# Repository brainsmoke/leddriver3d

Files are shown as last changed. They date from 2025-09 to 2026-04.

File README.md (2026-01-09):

# LED Driver for 3D sculptures based on an ESP32 with PSRAM + an STM32F0XX

     







# Design:

```
   programming &
  micropython REPL
         ||
     .--------.
     |  usb   |
     |   to   |  unified codebase       project specific firmware
     | serial |    /                            \
     '--------'   /                              \
         ||      /   standardized protocol        \
   .--------------.            |                  _____________.--
   |  ESP32-D0WD  |          (UART)              |             |-- multiple LED strands
   |   8M PSRAM   |-- 16bit/color LED frames --> |  STM32F0XX  |-- (temporal dithered)
   |  16M FLASH   |                              |_____________|--
   '--------------'                                            '--

```

# ESP Code `firmware/esp32/`

- Running micropython

- 60 FPS 16bit/color (48bit) animation with some routines written in C for speed.

- Animations use 3D-coordinates of the LEDs, as well as the direction they're pointing at

- Gamma correction & support for multiple LED orderings.

- Cached animation frames to prevent garbage collection hiccups

- Web interface (HTTPS capable, but no automatic cert. updates)

# STM32 Code `firmware/stm32/`

## Protocol

Sending a frame: `( [16 bit brightness]* [ FF FF FF F0 ] )*`

Brightness must be little endian integers in the (inclusive) range `[0 .. 0xFF00]`

`[ FF FF FF F0 ]` is an end of frame marker and allows the protocol to synchronize
in the event of an uneven number of bytes being written to the serial port

The firmware is completely agnostic about the color ordering.

Some of the following firmwares allow for tuning of the pulse interval:

`( [16 bit number]* [ FF FF FF F3 ] )*`

The given number is the number of cycles outputting a byte should take.
(Useful for increasing the FPS and thus improving temporal dithering.

## `dither16.bin`

Read in 16bit/color data in, drive 8 ws2812 LED strips in parallel

## `strip4.bin`

Read in 16bit/color data in, drive 4 ws2812 LED strips in parallel

## `strip5.bin`

Read in 16bit/color data in, drive 5 ws2812 LED strips in parallel,
Supports tuning the pulse interval.

## `relayball.bin`

Read in 16bit/color data in, drive 4 circuit-routed ws2812 LED meshes.
Small LED strands are connected through PADAUK based relay-chips
(`firmware/pdk/relay/`) that use in-band messages to build up routing
circuits.

## `uartball16.bin`

Drives up-to 8 busses with PADAUK based LED drivers which read 38400 baud
uart. `firmware/pdk/softpwm/`

##  `dither8.bin`

Older code using a different input protocol, reads 8bit/color data & transforms this to 16 bit colors
after gamma correction

# STM32 Tester code

## `jitter_timer.bin`

Tester for PADAUK ws2812 relay chips. `firmware/pdk/relay/`





Tests for functionality and measures the clock speed deviation (for binning).

## `timing_experiment.bin`

Dynamically adjust the `T1H` and `T1L` intervals from the ws2812 protocol to
test its limits.



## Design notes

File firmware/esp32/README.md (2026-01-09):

# ESP32 firmware upload / build

## Upload pre-built firmware

```bash
# make sure you are a member of the dailout group (so you can talk to the serial device)
sudo usermod -a -G dialout "$USER"
# you might need to log in again for it to take effect or you could do:
# (but newgrp only works for the current shell)
newgrp -

# install pip (using whatever package manager you have)
sudo apt install python3-pip

sudo pip3 install esptool
sudo pip3 install adafruit-ampy

# replace "/dev/ttyUSB0" with the correct device name
export ESPTTY="/dev/ttyUSB0"
tools/flash.sh
tools/micropython_screen.sh
ctrl-c
>>>setup()
(enter wifi creds, will be stored in flash)
>>>failsafe()
(enter failsafe wifi access point creds, will be stored in flash)
ctrl-d

```

For spheres other than the default 'greatcircles', replace `tools/flash.sh` with 
`tools/flash.sh <configuration>` (see: [[conf]](conf/)).

## Build firmware

```bash

# should be correct, but not tested from a clean VM

git clone https://github.com/brainsmoke/leddriver3d

# ESP-IDF
git clone -b v4.4.3 --recursive https://github.com/espressif/esp-idf.git
(cd esp-idf; ./install.sh)

# clone of micropython using esp32 native vfs, also has settings for http[s] server /mbedtls
git clone https://github.com/brainsmoke/micropython -b leddriver-post-1.19
(cd micropython/ports/esp32 ; make submodules)

# Edit setenv.sh to set the correct build directories:
cd leddriver3d/firmware/esp32
"$EDITOR" ./tools/setenv.sh

./tools/domake.sh
# firmware should be in micropython/ports/esp32/build-LEDBALL/firmware.bin

./tools/doflash.sh

```

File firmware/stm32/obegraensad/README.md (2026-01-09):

# IKEA OBEGRÄNSAD driver code

* Desolder the MCU (U1) on the bottom panel (looking at the silkscreen text, the panels are mounted upside down).
  It's the only chip that's only present on one of the boards.
* (Only) desolder the data-out to data-in wires connecting the panels (the potting compound can be easily removed with some isopropanol)
* All signals to the panel need to be boosted to 5V (for example using a 74HCT245)
* Leave the VCC/GND/CLK/Latch/Not-output-enable wires intact
* Connect the data-in pins to the leddriver3d board (or another board with an stm32f0xx running this firmware)
* Add ground wires next to the data wires for signal integrity
* The attached USB cable is power-only, but can be replaced
* The side-button is accessible via a pad on R5 on the bottom panel, it is pulled to ground when pressed.
* There is an alternative firmware for the STM32F042 which reads frames from USB-serial, see: [usb_proto/firmware/obegraensad](https://github.com/brainsmoke/usb_proto/tree/main/firmware/obegraensad)

close-up of the removed MCU footprint & pad to connect to the button

## Pinout (panel, data-in side):

Left-to-right, silkscreen orientation:

* VCC
* Latch
* Clock
* Data in
* Not Output Enable
* Ground

photo of pinout on the panels

## Pinout (driver board):

Output, boosted to 5V signalling:

* PA0: Data in, top panel
* PA1: Data in, 2nd panel
* PA2: Data in, 3rd panel
* PA3: Data in, bottom panel
* PA4: Clock (wired to bottom panel)
* PA5: Latch (wired to bottom panel)
* PA6: Not Output Enable (wired to bottom panel)

Input:

* PA10: UART RX, 1MBaud (In my case, written to by one the esp32's UARTs)

The pinout on the leddriver3d board (v4.0, with integrated level shifters):

photo of pinout on the leddriver3d board (v4.0)

## Protocol to the STM32 driver:

Signal: UART at 1MBaud

Sending a frame: `( [16 bit brightness]*256 [ FF FF FF F0 ] )*`

Brightness must be little endian integers in the (inclusive) range `[0 .. 0xFF00]`

One brightness value per pixel. Pixels are addressed left to right, top to bottom.

`[ FF FF FF F0 ]` is an end of frame marker and allows the protocol to synchronize
in the event of an uneven number of bytes being written to the serial port

## Picture of wiring setup

photo giving an overview of the wiring situation

## Animations software on the ESP32

My driver board contains an ESP32 which serves animations over a UART.
GPIO13 (uart-tx) of the ESP32 is connected to PA10 on the STM32 (uart-rx)

The ESP32 runs the animation software from [this repo](../../esp32).
instead of `tools/flash.sh`, run `tools/flash.sh obegraensad` to program the right configuration for this
project.

## Button

The button on the side connects to ground when pressed, and is accessable via a pad on the bottom panel.
I've connected it to GPIO2 of the ESP32 on my driver board.

## Other IKEA OBEGRÄNSAD hacks

[ph1h/ikea-led-obegraensad](https://github.com/ph1p/ikea-led-obegraensad)

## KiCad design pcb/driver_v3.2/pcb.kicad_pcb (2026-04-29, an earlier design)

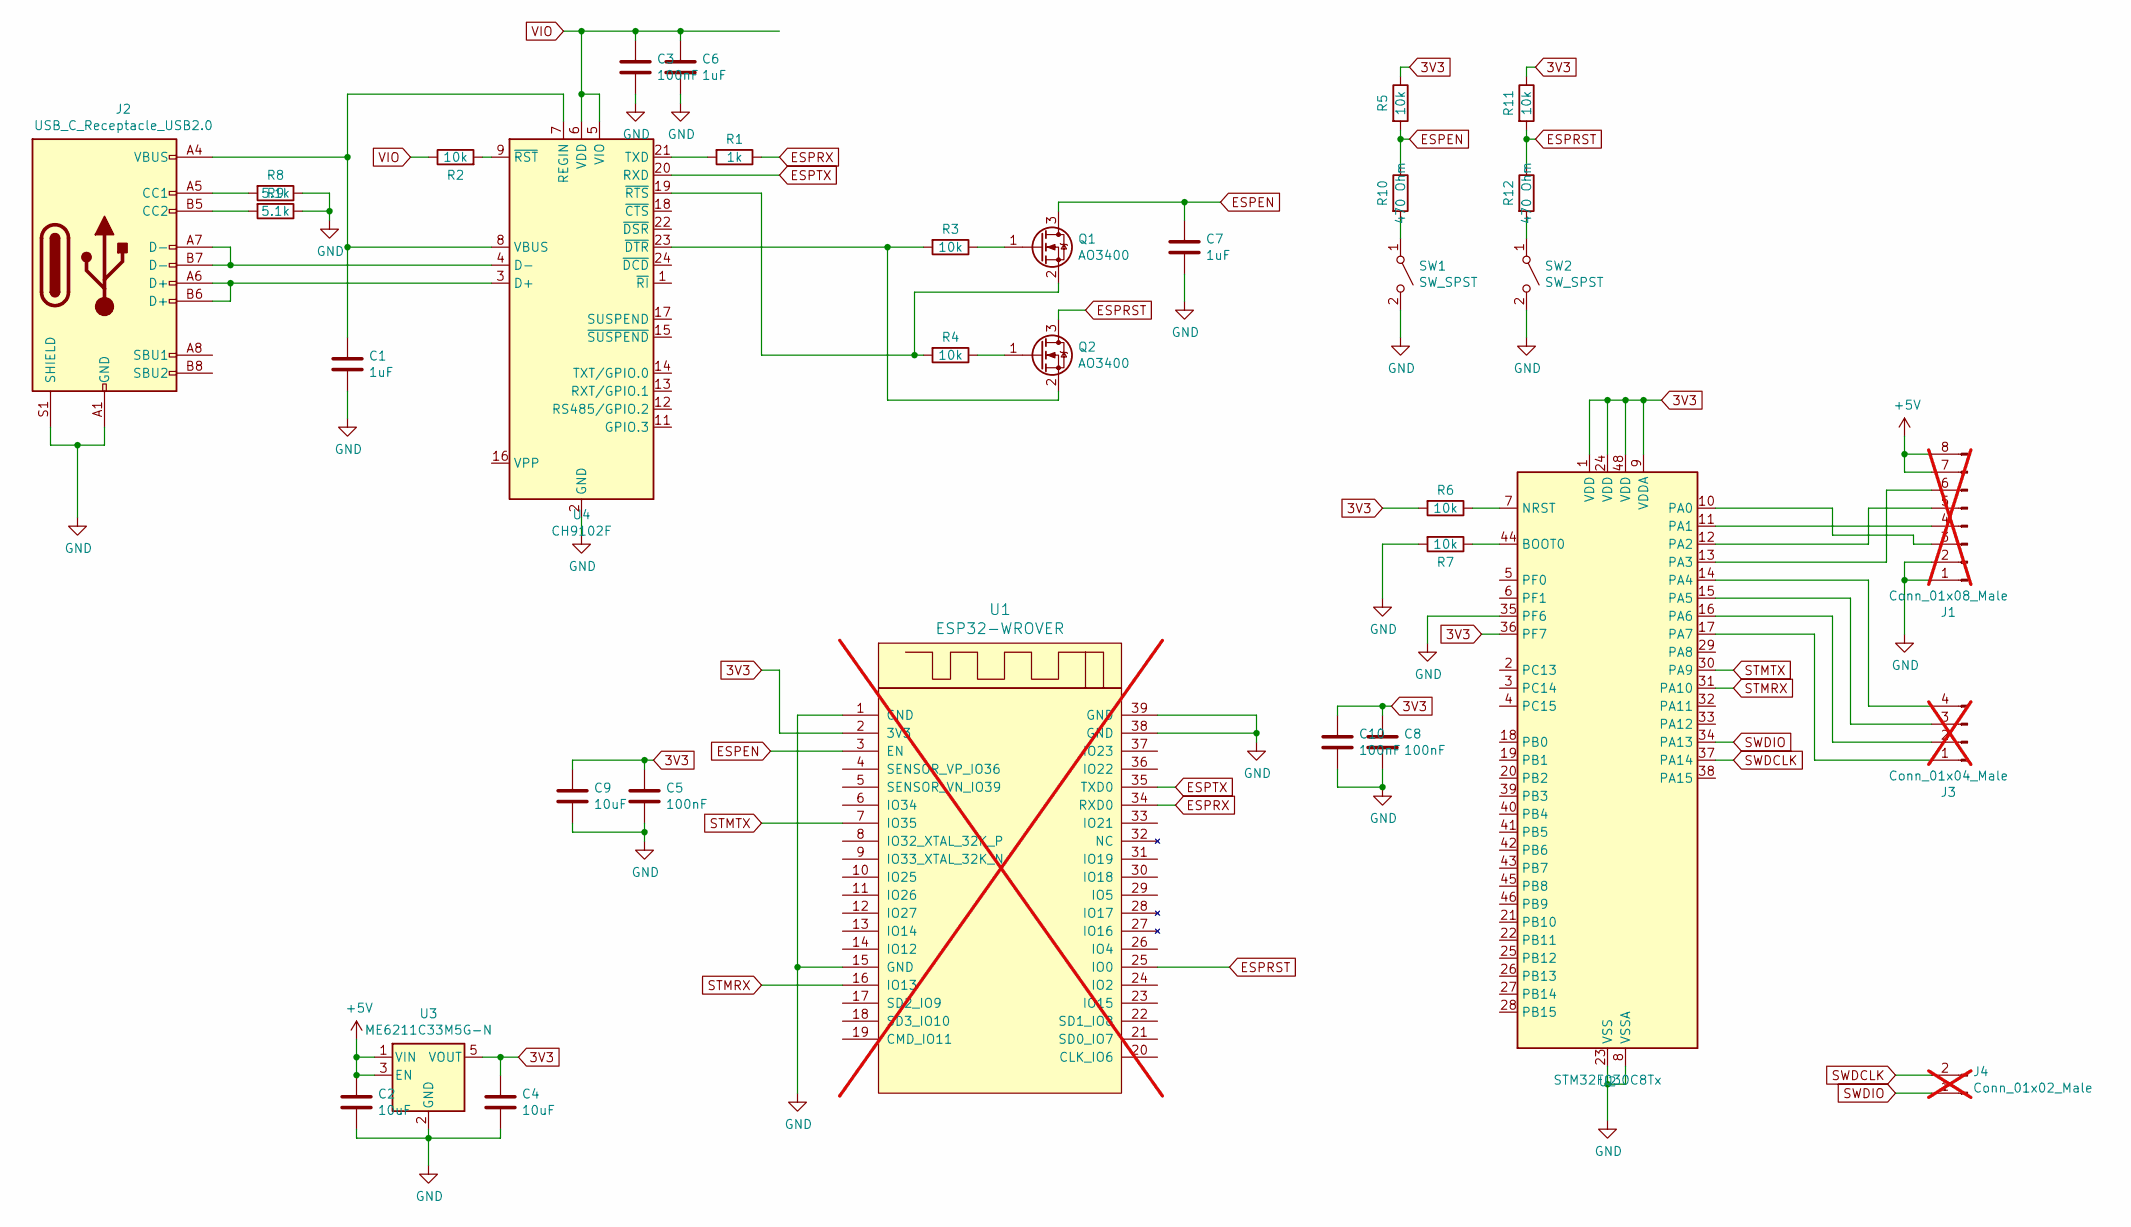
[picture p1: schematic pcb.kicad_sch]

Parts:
C1, C6, C7: 1uF; C_0402_1005Metric; LCSC C52923
C2, C4, C9: 10uF; C_0603_1608Metric; LCSC C19702
C3, C5, C8, C10: 100nF; C_0402_1005Metric; LCSC C1525
J1: Conn_01x08_Male; PinHeader_1x08_P2.54mm_Vertical; not fitted
J2: USB_C_Receptacle_USB2.0; USB_C_Receptacle_HRO_TYPE-C-31-M-12; LCSC C165948
J3: Conn_01x04_Male; PinHeader_1x04_P2.54mm_Vertical; not fitted
J4: Conn_01x02_Male; PinHeader_1x02_P2.54mm_Vertical; not fitted
Q1, Q2: AO3400; SOT-23; LCSC C20917
R1: 1k; R_0402_1005Metric; LCSC C11702
R2, R3, R4, R5, R6, R7, R11: 10k; R_0402_1005Metric; LCSC C25744
R8, R9: 5.1k; R_0402_1005Metric; LCSC C25905
R10, R12: 470 Ohm; R_0402_1005Metric; LCSC C25117
SW1, SW2: SW_SPST; SW_Push_1P1T_NO_CK_KMR2; LCSC C318893
U1: ESP32-WROVER; XCVR_ESP32-WROVER; not fitted
U2: STM32F030C8Tx; LQFP-48_7x7mm_P0.5mm; LCSC C23922
U3: ME6211C33M5G-N; SOT-23-5; LCSC C82942
U4: CH9102F; QFN-24-1EP_4x4mm_P0.5mm_EP2.6x2.6mm; LCSC C2858418

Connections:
3V3: C4.1, C5.1, C8.1, C9.1, C10.1, R5.1, R6.2, R11.1, U1.2 (3V3), U2.1 (VDD), U2.9 (VDDA), U2.24 (VDD), U2.36 (PF7), U2.48 (VDD), U3.5 (VOUT)
+5V: C2.1, J1.7, J1.8, U3.1 (VIN), U3.3 (EN)
ESPEN: C7.1, Q1.3 (D), R5.2, R10.1, U1.3 (EN)
ESPRST: Q2.3 (D), R11.2, R12.1, U1.25 (IO0)
ESPRX: R1.1, U1.34 (RXD0)
ESPTX: U1.35 (TXD0), U4.20 (RXD)
GND: C1.2, C2.2, C3.2, C4.2, C5.2, C6.2, C7.2, C8.2, C9.2, C10.2, J1.1, J1.2, J2.A1 (GND), J2.A12 (GND), J2.B1 (GND), J2.B12 (GND), J2.S1 (SHIELD), R7.2, R8.1, R9.1, SW1.2 (B), SW2.2 (B), U1.1 (GND), U1.15 (GND), U1.38 (GND), U1.39 (GND), U2.8 (VSSA), U2.23 (VSS), U2.35 (PF6), U2.47 (VSS), U3.2 (GND), U4.2 (GND), U4.25 (GND)
unnamed: J1.3, U2.10 (PA0)
unnamed: J1.4, U2.11 (PA1)
unnamed: J1.5, U2.12 (PA2)
unnamed: J1.6, U2.13 (PA3)
unnamed: J2.A5 (CC1), R8.2
unnamed: J2.B5 (CC2), R9.2
unnamed: J3.1, U2.17 (PA7)
unnamed: J3.2, U2.16 (PA6)
unnamed: J3.3, U2.15 (PA5)
unnamed: J3.4, U2.14 (PA4)
unnamed: Q1.1 (G), R3.1
unnamed: Q1.2 (S), R4.2, U4.19 (~RTS)
unnamed: Q2.1 (G), R4.1
unnamed: Q2.2 (S), R3.2, U4.23 (~DTR)
unnamed: R10.2, SW1.1 (A)
unnamed: R12.2, SW2.1 (A)
unnamed: R7.1, U2.44 (BOOT0)
unnamed: R6.1, U2.7 (NRST)
unnamed: J2.A6 (D+), J2.B6 (D+), U4.3 (D+)
unnamed: J2.A7 (D-), J2.B7 (D-), U4.4 (D-)
unnamed: C1.1, J2.A4 (VBUS), J2.A9 (VBUS), J2.B4 (VBUS), J2.B9 (VBUS), U4.7 (REGIN), U4.8 (VBUS)
unnamed: R1.2, U4.21 (TXD)
unnamed: R2.2, U4.9 (~RST)
STMRX: U1.16 (IO13), U2.31 (PA10)
STMTX: U1.7 (IO35), U2.30 (PA9)
SWDCLK: J4.2, U2.37 (PA14)
SWDIO: J4.1, U2.34 (PA13)
VIO: C3.1, C6.1, R2.1, U4.5 (VIO), U4.6 (VDD)

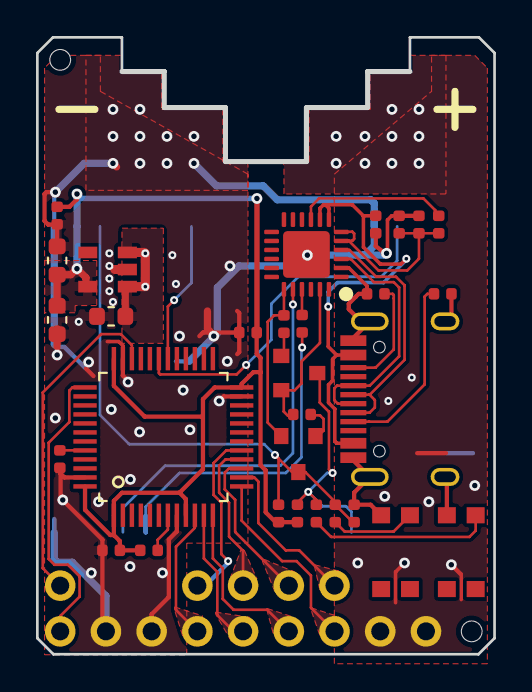
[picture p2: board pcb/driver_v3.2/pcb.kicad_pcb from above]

Board: 4 copper layers, 25.4 x 34.3 mm, 34 parts (1 on the bottom side), 35 nets.

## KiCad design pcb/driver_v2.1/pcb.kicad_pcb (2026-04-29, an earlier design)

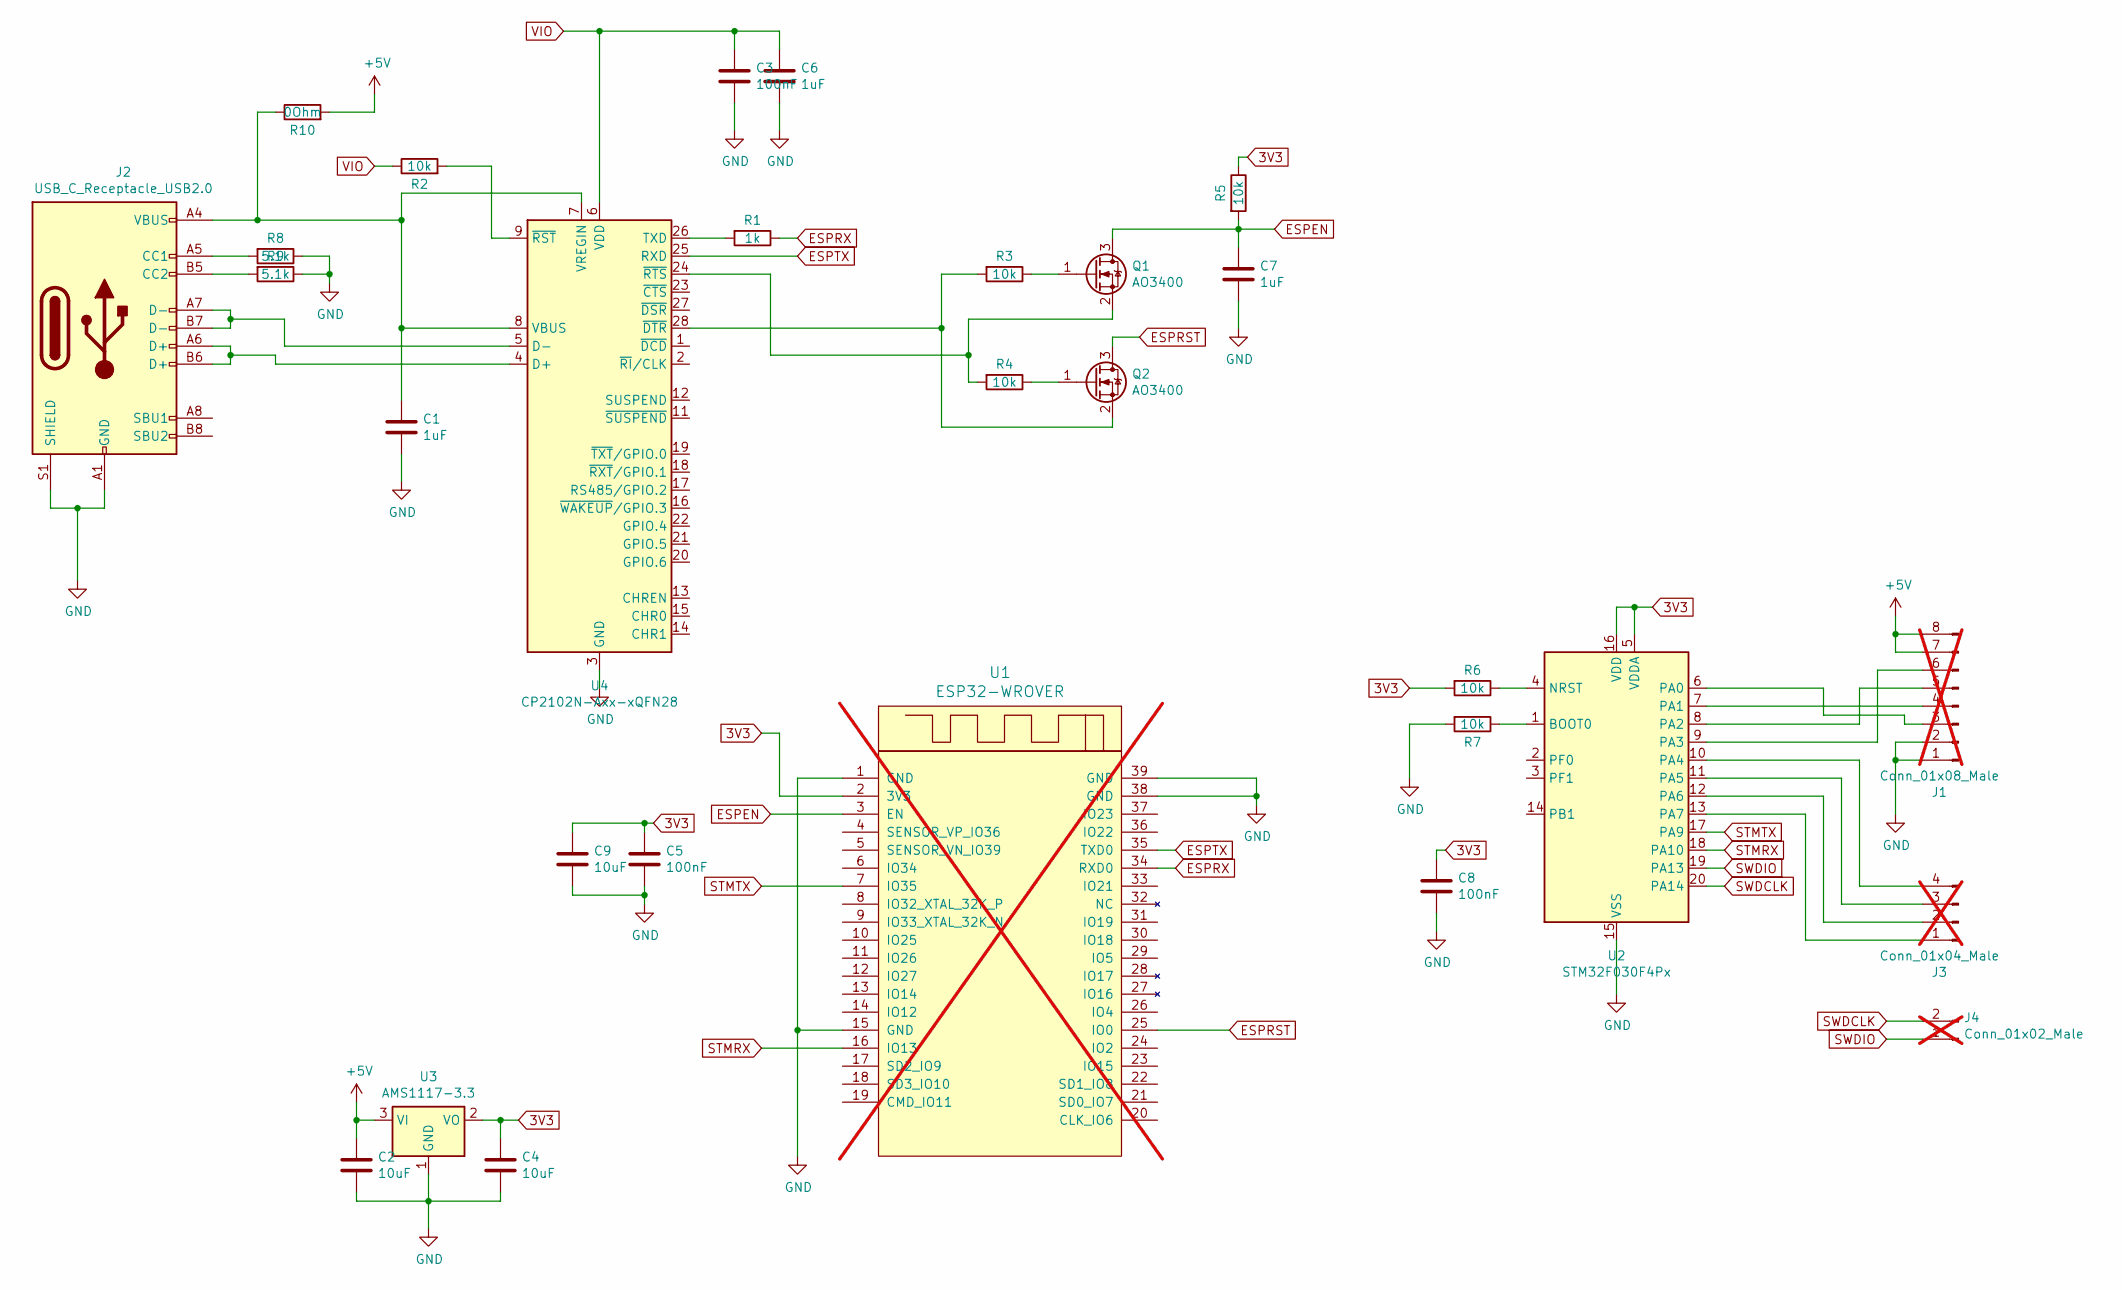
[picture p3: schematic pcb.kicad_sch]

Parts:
C1, C6, C7: 1uF; C_0603_1608Metric; LCSC C15849
C2, C4: 10uF; C_0603_1608Metric; LCSC C15850
C3, C5, C8: 100nF; C_0603_1608Metric; LCSC C14663
C9: 10uF; C_0603_1608Metric; LCSC C19702
J1: Conn_01x08_Male; PinHeader_1x08_P2.54mm_Vertical; not fitted
J2: USB_C_Receptacle_USB2.0; USB_C_Receptacle_HRO_TYPE-C-31-M-12; LCSC C165948
J3: Conn_01x04_Male; PinHeader_1x04_P2.54mm_Vertical; not fitted
J4: Conn_01x02_Male; PinHeader_1x02_P2.54mm_Vertical; not fitted
Q1, Q2: AO3400; SOT-23; LCSC C20917
R1: 1k; R_0603_1608Metric_nolabel; LCSC C21190
R2, R3, R4, R5, R6, R7: 10k; R_0603_1608Metric_nolabel; LCSC C25804
R8, R9: 5.1k; R_0603_1608Metric_nolabel; LCSC C23186
R10: 0Ohm; R_0603_1608Metric_nolabel; LCSC C25804
U1: ESP32-WROVER; XCVR_ESP32-WROVER; not fitted
U2: STM32F030F4Px; TSSOP-20_4.4x6.5mm_P0.65mm; LCSC C89040
U3: AMS1117-3.3; SOT-223-3_TabPin2; LCSC C6186
U4: CP2102N-Axx-xQFN28; QFN-28-1EP_5x5mm_P0.5mm_EP3.35x3.35mm; LCSC C6568

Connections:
3V3: C4.1, C5.1, C8.1, C9.1, R5.1, R6.2, U1.2 (3V3), U2.5 (VDDA), U2.16 (VDD), U3.2 (VO)
+5V: C2.1, J1.7, J1.8, R10.2, U3.3 (VI)
ESPEN: C7.1, Q1.3 (D), R5.2, U1.3 (EN)
ESPRST: Q2.3 (D), U1.25 (IO0)
ESPRX: R1.1, U1.34 (RXD0)
ESPTX: U1.35 (TXD0), U4.25 (RXD)
GND: C1.2, C2.2, C3.2, C4.2, C5.2, C6.2, C7.2, C8.2, C9.2, J1.1, J1.2, J2.A1 (GND), J2.A12 (GND), J2.B1 (GND), J2.B12 (GND), J2.S1 (SHIELD), R7.2, R8.1, R9.1, U1.1 (GND), U1.15 (GND), U1.38 (GND), U1.39 (GND), U2.15 (VSS), U3.1 (GND), U4.3 (GND), U4.29 (GND)
unnamed: J1.3, U2.6 (PA0)
unnamed: J1.4, U2.7 (PA1)
unnamed: J1.5, U2.8 (PA2)
unnamed: J1.6, U2.9 (PA3)
unnamed: J2.A5 (CC1), R8.2
unnamed: J2.B5 (CC2), R9.2
unnamed: J3.1, U2.13 (PA7)
unnamed: J3.2, U2.12 (PA6)
unnamed: J3.3, U2.11 (PA5)
unnamed: J3.4, U2.10 (PA4)
unnamed: Q1.1 (G), R3.1
unnamed: Q1.2 (S), R4.2, U4.24 (~RTS)
unnamed: Q2.1 (G), R4.1
unnamed: Q2.2 (S), R3.2, U4.28 (~DTR)
unnamed: R7.1, U2.1 (BOOT0)
unnamed: R6.1, U2.4 (NRST)
unnamed: J2.A6 (D+), J2.B6 (D+), U4.4 (D+)
unnamed: J2.A7 (D-), J2.B7 (D-), U4.5 (D-)
unnamed: R1.2, U4.26 (TXD)
unnamed: C1.1, J2.A4 (VBUS), J2.A9 (VBUS), J2.B4 (VBUS), J2.B9 (VBUS), R10.1, U4.7 (VREGIN), U4.8 (VBUS)
unnamed: R2.2, U4.9 (~RST)
STMRX: U1.16 (IO13), U2.18 (PA10)
STMTX: U1.7 (IO35), U2.17 (PA9)
SWDCLK: J4.2, U2.20 (PA14)
SWDIO: J4.1, U2.19 (PA13)
VIO: C3.1, C6.1, R2.1, U4.6 (VDD)

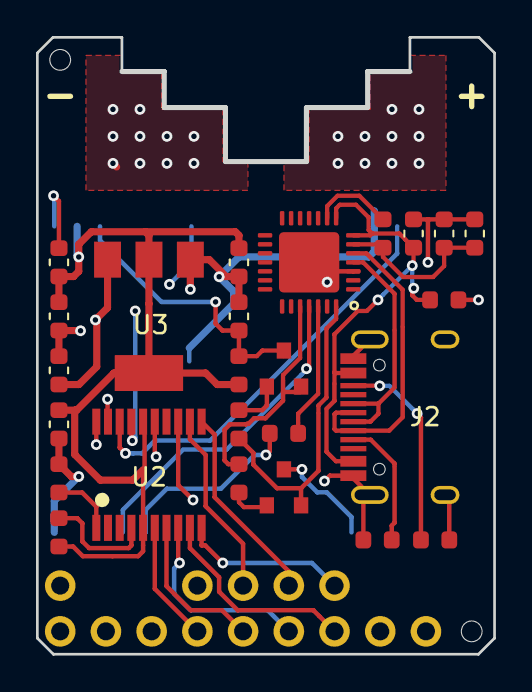
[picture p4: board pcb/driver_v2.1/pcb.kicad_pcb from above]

Board: 4 copper layers, 25.4 x 34.3 mm, 29 parts (1 on the bottom side), 33 nets.

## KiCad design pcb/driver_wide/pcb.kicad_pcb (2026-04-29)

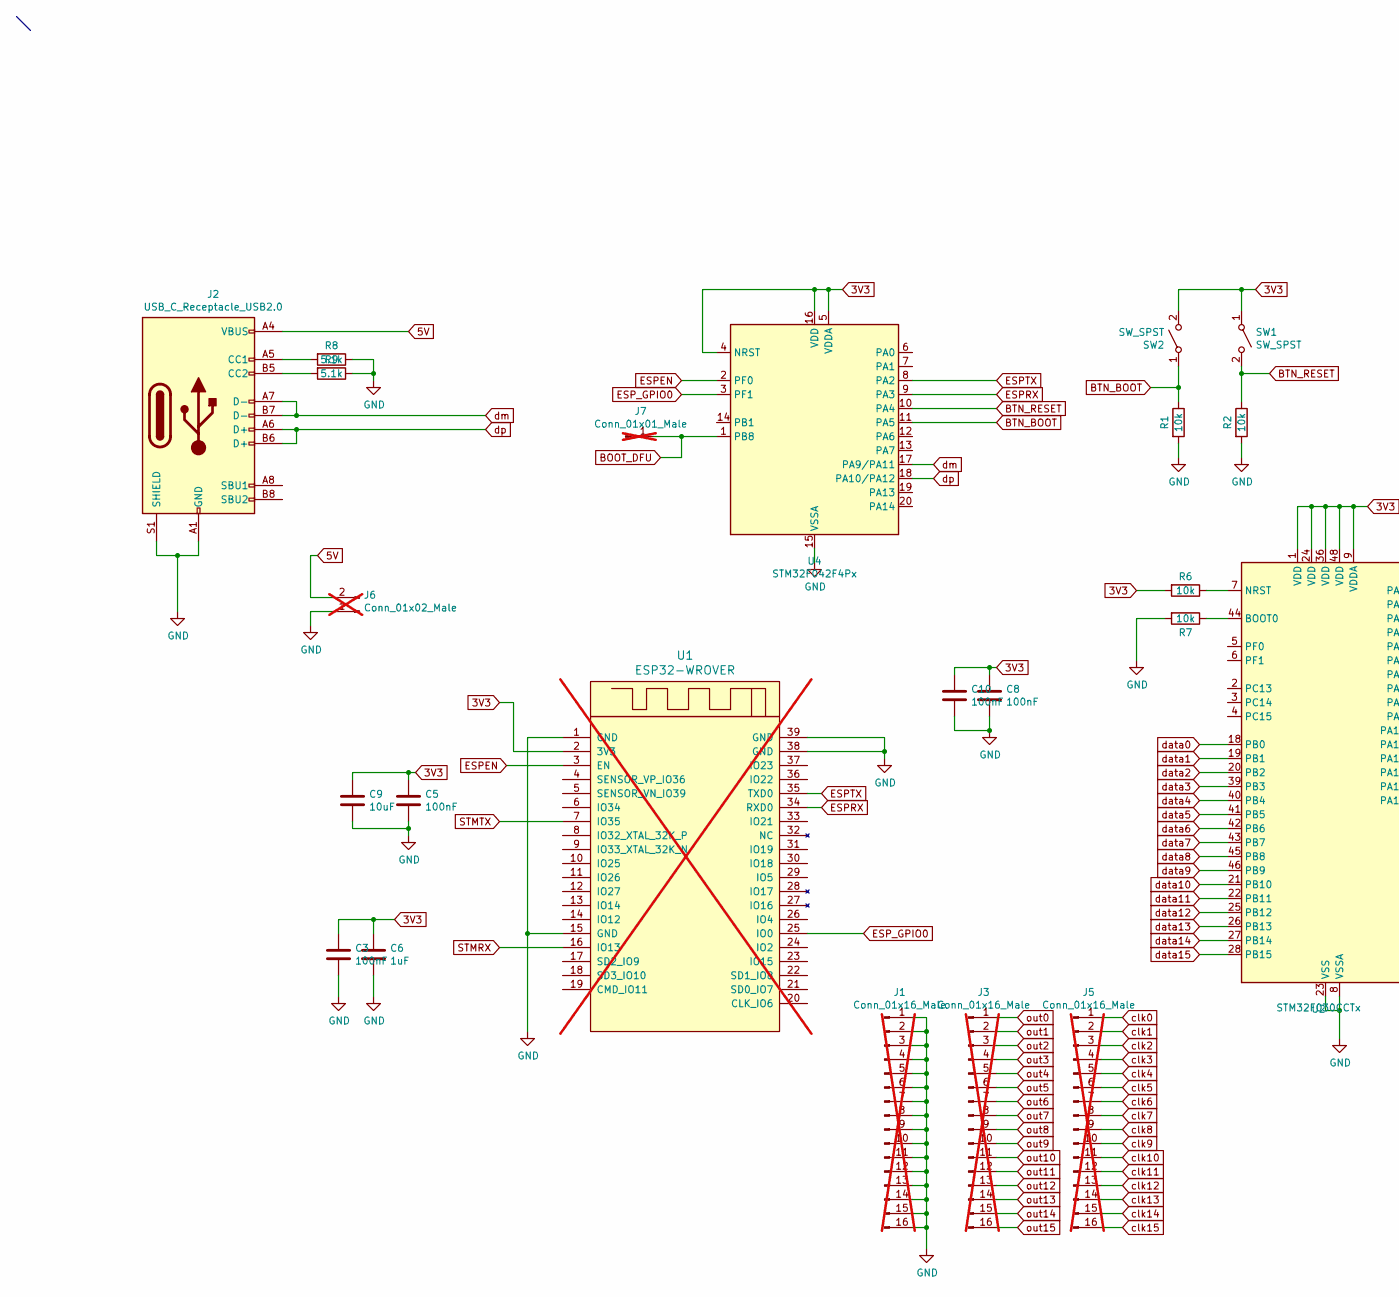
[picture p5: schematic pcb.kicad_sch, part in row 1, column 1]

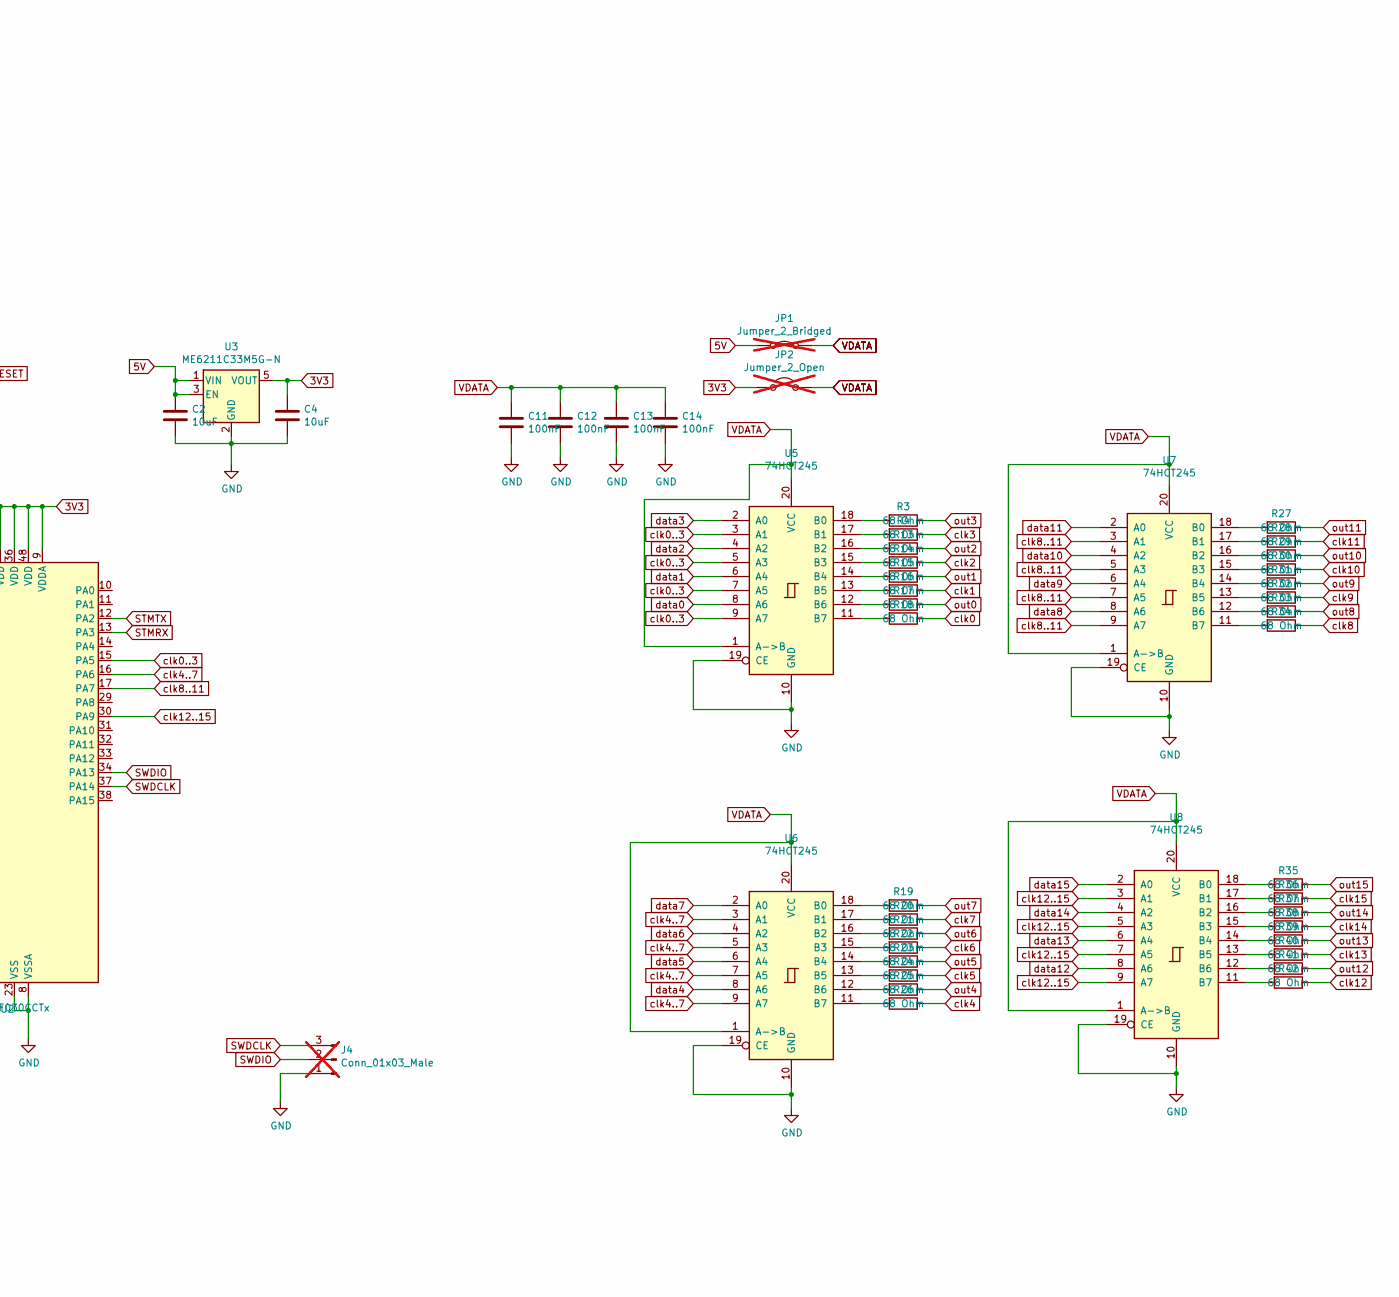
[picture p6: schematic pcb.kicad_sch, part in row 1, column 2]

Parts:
C2, C4, C9: 10uF; C_0603_1608Metric; LCSC C19702
C3, C5, C8, C10: 100nF; C_0402_1005Metric; LCSC C1525
C6: 1uF; C_0402_1005Metric; LCSC C52923
C11, C12, C13, C14: 100nF; C_0402_1005Metric; LCSC C19702
J1, J3, J5: Conn_01x16_Male; PinHeader_1x16_P2.54mm_Vertical; not fitted
J2: USB_C_Receptacle_USB2.0; USB_C_Receptacle_HRO_TYPE-C-31-M-12; LCSC C165948
J4: Conn_01x03_Male; PinHeader_1x03_P2.54mm_Vertical; not fitted
J6: Conn_01x02_Male; PinHeader_1x02_P2.54mm_Vertical; not fitted
J7: Conn_01x01_Male; PinHeader_1x01_P2.54mm_Vertical; not fitted
JP1: Jumper_2_Bridged; SolderJumper-2_P1.3mm_Bridged_Pad1.0x1.5mm; not fitted
JP2: Jumper_2_Open; SolderJumper-2_P1.3mm_Open_Pad1.0x1.5mm; not fitted
R1, R2, R6, R7: 10k; R_0402_1005Metric; LCSC C25744
R3, R4, R13, R14, R15, R16, R17, R18, R19, R20, R21, R22, R23, R24, R25, R26, R27, R28, R29, R30, R31, R32, R33, R34, R35, R36, R37, R38, R39, R40, R41, R42: 68 Ohm; R_0402_1005Metric; LCSC C25744
R8, R9: 5.1k; R_0402_1005Metric; LCSC C25905
SW1, SW2: SW_SPST; SW_Push_1P1T_NO_CK_KMR2; LCSC C318893
U1: ESP32-WROVER; XCVR_ESP32-WROVER; not fitted
U2: STM32F030CCTx; LQFP-48_7x7mm_P0.5mm; LCSC C81787
U3: ME6211C33M5G-N; SOT-23-5; LCSC C82942
U4: STM32F042F4Px; TSSOP-20_4.4x6.5mm_P0.65mm; LCSC C81000
U5, U6, U7, U8: 74HCT245; TSSOP-20_4.4x6.5mm_P0.65mm; LCSC C5980

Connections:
3V3: C3.1, C4.1, C5.1, C6.1, C8.1, C9.1, C10.1, JP2.1 (A), R6.2, SW1.1 (A), SW2.2 (B), U1.2 (3V3), U2.1 (VDD), U2.9 (VDDA), U2.24 (VDD), U2.36 (VDD), U2.48 (VDD), U3.5 (VOUT), U4.4 (NRST), U4.5 (VDDA), U4.16 (VDD)
5V: C2.1, J2.A4 (VBUS), J2.A9 (VBUS), J2.B4 (VBUS), J2.B9 (VBUS), J6.2, JP1.1 (A), U3.1 (VIN), U3.3 (EN)
BOOT_DFU: J7.1, U4.1 (PB8)
BTN_BOOT: R1.1, SW2.1 (A), U4.11 (PA5)
BTN_RESET: R2.1, SW1.2 (B), U4.10 (PA4)
ESPEN: U1.3 (EN), U4.2 (PF0)
ESPRX: U1.34 (RXD0), U4.9 (PA3)
ESPTX: U1.35 (TXD0), U4.8 (PA2)
ESP_GPIO0: U1.25 (IO0), U4.3 (PF1)
GND: C2.2, C3.2, C4.2, C5.2, C6.2, C8.2, C9.2, C10.2, C11.2, C12.2, C13.2, C14.2, J1.1, J1.2, J1.3, J1.4, J1.5, J1.6, J1.7, J1.8, J1.9, J1.10, J1.11, J1.12, J1.13, J1.14, J1.15, J1.16, J2.A1 (GND), J2.A12 (GND), J2.B1 (GND), J2.B12 (GND), J2.S1 (SHIELD), J4.1, J6.1, R1.2, R2.2, R7.2, R8.1, R9.1, U1.1 (GND), U1.15 (GND), U1.38 (GND), U1.39 (GND), U2.8 (VSSA), U2.23 (VSS), U2.35 (VSS), U2.47 (VSS), U3.2 (GND), U4.15 (VSSA), U5.10 (GND), U5.19 (CE), U6.10 (GND), U6.19 (CE), U7.10 (GND), U7.19 (CE), U8.10 (GND), U8.19 (CE)
unnamed: J2.A5 (CC1), R8.2
unnamed: J2.B5 (CC2), R9.2
unnamed: R7.1, U2.44 (BOOT0)
unnamed: R6.1, U2.7 (NRST)
unnamed: R3.2, U5.18 (B0)
unnamed: R4.2, U5.17 (B1)
unnamed: R13.2, U5.16 (B2)
unnamed: R14.2, U5.15 (B3)
unnamed: R15.2, U5.14 (B4)
unnamed: R16.2, U5.13 (B5)
unnamed: R17.2, U5.12 (B6)
unnamed: R18.2, U5.11 (B7)
unnamed: R19.2, U6.18 (B0)
unnamed: R20.2, U6.17 (B1)
unnamed: R21.2, U6.16 (B2)
unnamed: R22.2, U6.15 (B3)
unnamed: R23.2, U6.14 (B4)
unnamed: R24.2, U6.13 (B5)
unnamed: R25.2, U6.12 (B6)
unnamed: R26.2, U6.11 (B7)
unnamed: R27.2, U7.18 (B0)
unnamed: R28.2, U7.17 (B1)
unnamed: R29.2, U7.16 (B2)
unnamed: R30.2, U7.15 (B3)
unnamed: R31.2, U7.14 (B4)
unnamed: R32.2, U7.13 (B5)
unnamed: R33.2, U7.12 (B6)
unnamed: R34.2, U7.11 (B7)
unnamed: R35.2, U8.18 (B0)
unnamed: R36.2, U8.17 (B1)
unnamed: R37.2, U8.16 (B2)
unnamed: R38.2, U8.15 (B3)
unnamed: R39.2, U8.14 (B4)
unnamed: R40.2, U8.13 (B5)
unnamed: R41.2, U8.12 (B6)
unnamed: R42.2, U8.11 (B7)
STMRX: U1.16 (IO13), U2.13 (PA3)
STMTX: U1.7 (IO35), U2.12 (PA2)
SWDCLK: J4.3, U2.37 (PA14)
SWDIO: J4.2, U2.34 (PA13)
VDATA: C11.1, C12.1, C13.1, C14.1, JP1.2 (B), JP2.2 (B), U5.1 (A->B), U5.20 (VCC), U6.1 (A->B), U6.20 (VCC), U7.1 (A->B), U7.20 (VCC), U8.1 (A->B), U8.20 (VCC)
clk0: J5.1, R18.1
clk0..3: U2.15 (PA5), U5.3 (A1), U5.5 (A3), U5.7 (A5), U5.9 (A7)
clk1: J5.2, R16.1
clk2: J5.3, R14.1
clk3: J5.4, R4.1
clk4: J5.5, R26.1
clk4..7: U2.16 (PA6), U6.3 (A1), U6.5 (A3), U6.7 (A5), U6.9 (A7)
clk5: J5.6, R24.1
clk6: J5.7, R22.1
clk7: J5.8, R20.1
clk8: J5.9, R34.1
clk8..11: U2.17 (PA7), U7.3 (A1), U7.5 (A3), U7.7 (A5), U7.9 (A7)
clk9: J5.10, R32.1
clk10: J5.11, R30.1
clk11: J5.12, R28.1
clk12: J5.13, R42.1
clk12..15: U2.30 (PA9), U8.3 (A1), U8.5 (A3), U8.7 (A5), U8.9 (A7)
clk13: J5.14, R40.1
clk14: J5.15, R38.1
clk15: J5.16, R36.1
data0: U2.18 (PB0), U5.8 (A6)
data1: U2.19 (PB1), U5.6 (A4)
data2: U2.20 (PB2), U5.4 (A2)
data3: U2.39 (PB3), U5.2 (A0)
data4: U2.40 (PB4), U6.8 (A6)
data5: U2.41 (PB5), U6.6 (A4)
data6: U2.42 (PB6), U6.4 (A2)
data7: U2.43 (PB7), U6.2 (A0)
data8: U2.45 (PB8), U7.8 (A6)
data9: U2.46 (PB9), U7.6 (A4)
data10: U2.21 (PB10), U7.4 (A2)
data11: U2.22 (PB11), U7.2 (A0)
data12: U2.25 (PB12), U8.8 (A6)
data13: U2.26 (PB13), U8.6 (A4)
data14: U2.27 (PB14), U8.4 (A2)
data15: U2.28 (PB15), U8.2 (A0)
dm: J2.A7 (D-), J2.B7 (D-), U4.17 (PA9/PA11)
dp: J2.A6 (D+), J2.B6 (D+), U4.18 (PA10/PA12)
out0: J3.1, R17.1
out1: J3.2, R15.1
out2: J3.3, R13.1
out3: J3.4, R3.1
out4: J3.5, R25.1
out5: J3.6, R23.1
out6: J3.7, R21.1
out7: J3.8, R19.1
out8: J3.9, R33.1
out9: J3.10, R31.1
out10: J3.11, R29.1
out11: J3.12, R27.1
out12: J3.13, R41.1
out13: J3.14, R39.1
out14: J3.15, R37.1
out15: J3.16, R35.1

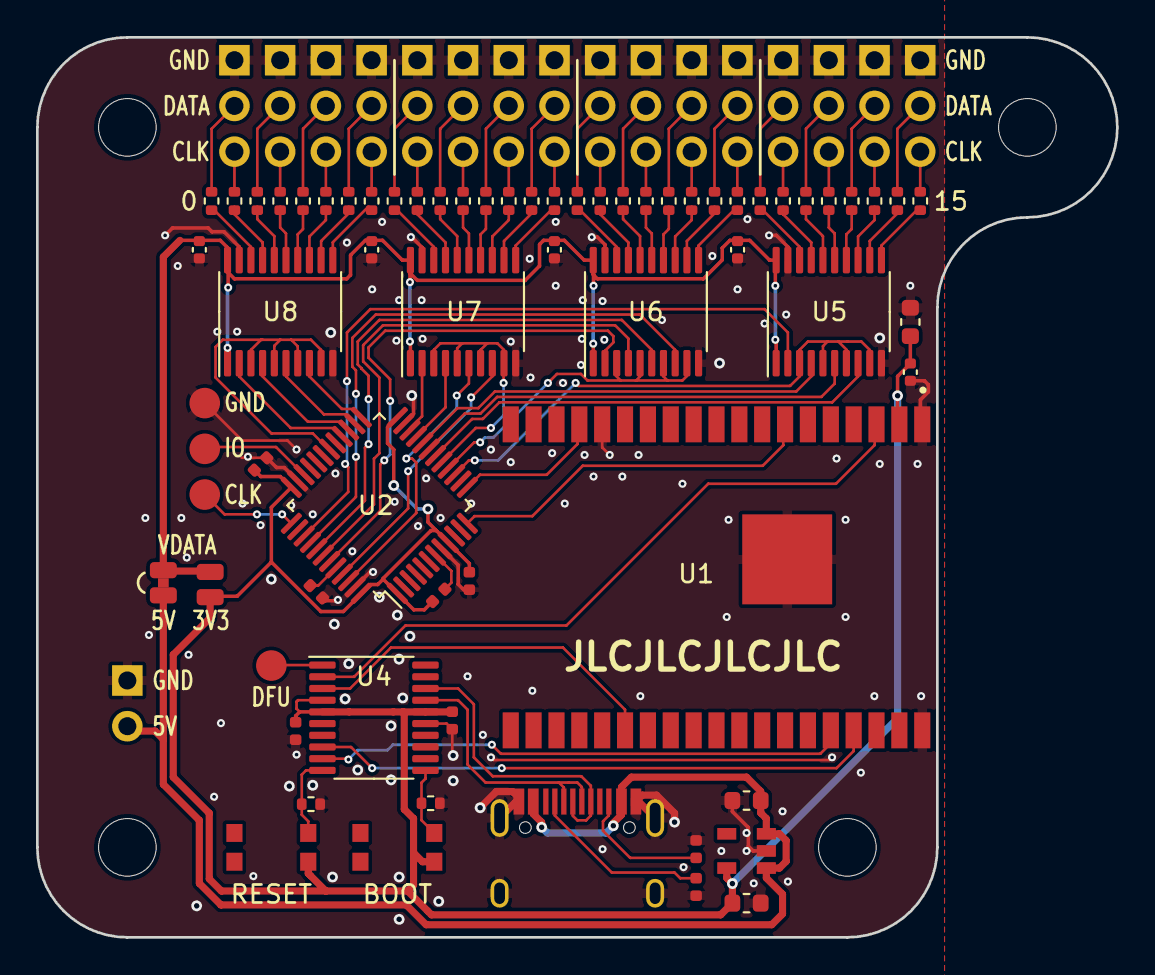
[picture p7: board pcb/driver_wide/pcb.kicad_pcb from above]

Board: 2 copper layers, 60.0 x 50.0 mm, 69 parts (0 on the bottom side), 105 nets.

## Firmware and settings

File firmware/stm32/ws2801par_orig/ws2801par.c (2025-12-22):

#include <stdlib.h>
#include <string.h>
#include "stm32f0xx.h"

#include "ws2801par.h"
#include "util.h"

typedef struct
{
	transposed_t transpose[N_VALUES_PER_STRIP];
	uint8_t low_bytes[N_VALUES];

} frame_t;

frame_t frame_a, frame_b;

uint8_t residual[N_VALUES];
frame_t * volatile cur;
frame_t * volatile next;

#define RECV_BUF_SZ (2048)
volatile uint8_t recv_buf[RECV_BUF_SZ];

/*
# emulate original single strip order expected by software
facet_order = [
    21,22, 1,19,15,16,17,18, 2, 6, 7, 8, 9, 5, 3,
    52,53,54,50,51, 4,12,13,14,10,11, 0,23,24,20,
    34,30,44,35,36,37,38,39,40,49,45,46,47,48,41,
    59,55,56,57,58,42,26,27,28,29,25,43,31,32,33
]

led_order = [ f*5+l for f in facet_order for l in range(5) ]

byte_order = [ l*3+c for l in led_order for c in (0,1,2) ]

n_strips = 12
n_bytes_per_strip = len(byte_order)//n_strips
n_values = n_strips*n_bytes_per_strip
assert len(byte_order) == n_values

*/
static const uint16_t low_byte_index[] = 
{
/*

# byte 0 strip 0, byte 0 strip 1, ...
scattered = [ None ] * n_values

for i in range(len(byte_order)):
    scattered[i] = (byte_order[i]%n_bytes_per_strip)*n_strips + byte_order[i]//n_bytes_per_strip

for line in range(0, n_values, 15):
    print("\t" + ''.join('{:4d},'.format(n) for n in scattered[line:line+15]))
*/
	 184, 196, 208, 220, 232, 244, 256, 268, 280, 292, 304, 316, 328, 340, 352,
	 364, 376, 388, 400, 412, 424, 436, 448, 460, 472, 484, 496, 508, 520, 532,
	 180, 192, 204, 216, 228, 240, 252, 264, 276, 288, 300, 312, 324, 336, 348,
	 723, 735, 747, 759, 771, 783, 795, 807, 819, 831, 843, 855, 867, 879, 891,
	   3,  15,  27,  39,  51,  63,  75,  87,  99, 111, 123, 135, 147, 159, 171,
	 183, 195, 207, 219, 231, 243, 255, 267, 279, 291, 303, 315, 327, 339, 351,
	 363, 375, 387, 399, 411, 423, 435, 447, 459, 471, 483, 495, 507, 519, 531,
	 543, 555, 567, 579, 591, 603, 615, 627, 639, 651, 663, 675, 687, 699, 711,
	 360, 372, 384, 396, 408, 420, 432, 444, 456, 468, 480, 492, 504, 516, 528,
	 181, 193, 205, 217, 229, 241, 253, 265, 277, 289, 301, 313, 325, 337, 349,
	 361, 373, 385, 397, 409, 421, 433, 445, 457, 469, 481, 493, 505, 517, 529,
	 541, 553, 565, 577, 589, 601, 613, 625, 637, 649, 661, 673, 685, 697, 709,
	 721, 733, 745, 757, 769, 781, 793, 805, 817, 829, 841, 853, 865, 877, 889,
	   1,  13,  25,  37,  49,  61,  73,  85,  97, 109, 121, 133, 145, 157, 169,
	 540, 552, 564, 576, 588, 600, 612, 624, 636, 648, 660, 672, 684, 696, 708,
	 370, 382, 394, 406, 418, 430, 442, 454, 466, 478, 490, 502, 514, 526, 538,
	 550, 562, 574, 586, 598, 610, 622, 634, 646, 658, 670, 682, 694, 706, 718,
	 730, 742, 754, 766, 778, 790, 802, 814, 826, 838, 850, 862, 874, 886, 898,
	  10,  22,  34,  46,  58,  70,  82,  94, 106, 118, 130, 142, 154, 166, 178,
	 190, 202, 214, 226, 238, 250, 262, 274, 286, 298, 310, 322, 334, 346, 358,
	 720, 732, 744, 756, 768, 780, 792, 804, 816, 828, 840, 852, 864, 876, 888,
	 362, 374, 386, 398, 410, 422, 434, 446, 458, 470, 482, 494, 506, 518, 530,
	 542, 554, 566, 578, 590, 602, 614, 626, 638, 650, 662, 674, 686, 698, 710,
	 722, 734, 746, 758, 770, 782, 794, 806, 818, 830, 842, 854, 866, 878, 890,
	   2,  14,  26,  38,  50,  62,  74,  86,  98, 110, 122, 134, 146, 158, 170,
	 182, 194, 206, 218, 230, 242, 254, 266, 278, 290, 302, 314, 326, 338, 350,
	   0,  12,  24,  36,  48,  60,  72,  84,  96, 108, 120, 132, 144, 156, 168,
	 544, 556, 568, 580, 592, 604, 616, 628, 640, 652, 664, 676, 688, 700, 712,
	 724, 736, 748, 760, 772, 784, 796, 808, 820, 832, 844, 856, 868, 880, 892,
	   4,  16,  28,  40,  52,  64,  76,  88, 100, 112, 124, 136, 148, 160, 172,
	 726, 738, 750, 762, 774, 786, 798, 810, 822, 834, 846, 858, 870, 882, 894,
	   6,  18,  30,  42,  54,  66,  78,  90, 102, 114, 126, 138, 150, 162, 174,
	 728, 740, 752, 764, 776, 788, 800, 812, 824, 836, 848, 860, 872, 884, 896,
	   7,  19,  31,  43,  55,  67,  79,  91, 103, 115, 127, 139, 151, 163, 175,
	 187, 199, 211, 223, 235, 247, 259, 271, 283, 295, 307, 319, 331, 343, 355,
	 367, 379, 391, 403, 415, 427, 439, 451, 463, 475, 487, 499, 511, 523, 535,
	 547, 559, 571, 583, 595, 607, 619, 631, 643, 655, 667, 679, 691, 703, 715,
	 727, 739, 751, 763, 775, 787, 799, 811, 823, 835, 847, 859, 871, 883, 895,
	   8,  20,  32,  44,  56,  68,  80,  92, 104, 116, 128, 140, 152, 164, 176,
	 729, 741, 753, 765, 777, 789, 801, 813, 825, 837, 849, 861, 873, 885, 897,
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
};

static const uint8_t high_byte_index[] = 
{
/*
for line in range(0, n_values, 30):
    print("\t" + ''.join('{:2d},'.format(n//12) for n in scattered[line:line+30]))
*/
	15,16,17,18,19,20,21,22,23,24,25,26,27,28,29,30,31,32,33,34,35,36,37,38,39,40,41,42,43,44,
	15,16,17,18,19,20,21,22,23,24,25,26,27,28,29,60,61,62,63,64,65,66,67,68,69,70,71,72,73,74,
	 0, 1, 2, 3, 4, 5, 6, 7, 8, 9,10,11,12,13,14,15,16,17,18,19,20,21,22,23,24,25,26,27,28,29,
	30,31,32,33,34,35,36,37,38,39,40,41,42,43,44,45,46,47,48,49,50,51,52,53,54,55,56,57,58,59,
	30,31,32,33,34,35,36,37,38,39,40,41,42,43,44,15,16,17,18,19,20,21,22,23,24,25,26,27,28,29,
	30,31,32,33,34,35,36,37,38,39,40,41,42,43,44,45,46,47,48,49,50,51,52,53,54,55,56,57,58,59,
	60,61,62,63,64,65,66,67,68,69,70,71,72,73,74, 0, 1, 2, 3, 4, 5, 6, 7, 8, 9,10,11,12,13,14,
	45,46,47,48,49,50,51,52,53,54,55,56,57,58,59,30,31,32,33,34,35,36,37,38,39,40,41,42,43,44,
	45,46,47,48,49,50,51,52,53,54,55,56,57,58,59,60,61,62,63,64,65,66,67,68,69,70,71,72,73,74,
	 0, 1, 2, 3, 4, 5, 6, 7, 8, 9,10,11,12,13,14,15,16,17,18,19,20,21,22,23,24,25,26,27,28,29,
	60,61,62,63,64,65,66,67,68,69,70,71,72,73,74,30,31,32,33,34,35,36,37,38,39,40,41,42,43,44,
	45,46,47,48,49,50,51,52,53,54,55,56,57,58,59,60,61,62,63,64,65,66,67,68,69,70,71,72,73,74,
	 0, 1, 2, 3, 4, 5, 6, 7, 8, 9,10,11,12,13,14,15,16,17,18,19,20,21,22,23,24,25,26,27,28,29,
	 0, 1, 2, 3, 4, 5, 6, 7, 8, 9,10,11,12,13,14,45,46,47,48,49,50,51,52,53,54,55,56,57,58,59,
	60,61,62,63,64,65,66,67,68,69,70,71,72,73,74, 0, 1, 2, 3, 4, 5, 6, 7, 8, 9,10,11,12,13,14,
	60,61,62,63,64,65,66,67,68,69,70,71,72,73,74, 0, 1, 2, 3, 4, 5, 6, 7, 8, 9,10,11,12,13,14,
	60,61,62,63,64,65,66,67,68,69,70,71,72,73,74, 0, 1, 2, 3, 4, 5, 6, 7, 8, 9,10,11,12,13,14,
	15,16,17,18,19,20,21,22,23,24,25,26,27,28,29,30,31,32,33,34,35,36,37,38,39,40,41,42,43,44,
	45,46,47,48,49,50,51,52,53,54,55,56,57,58,59,60,61,62,63,64,65,66,67,68,69,70,71,72,73,74,
	 0, 1, 2, 3, 4, 5, 6, 7, 8, 9,10,11,12,13,14,60,61,62,63,64,65,66,67,68,69,70,71,72,73,74,
	 0, 1, 2, 3, 4, 5, 6, 7, 8, 9,10,11,12,13,14,15,16,17,18,19,20,21,22,23,24,25,26,27,28,29,
	30,31,32,33,34,35,36,37,38,39,40,41,42,43,44,45,46,47,48,49,50,51,52,53,54,55,56,57,58,59,
	15,16,17,18,19,20,21,22,23,24,25,26,27,28,29,60,61,62,63,64,65,66,67,68,69,70,71,72,73,74,
	 0, 1, 2, 3, 4, 5, 6, 7, 8, 9,10,11,12,13,14,15,16,17,18,19,20,21,22,23,24,25,26,27,28,29,
	30,31,32,33,34,35,36,37,38,39,40,41,42,43,44,45,46,47,48,49,50,51,52,53,54,55,56,57,58,59,
	30,31,32,33,34,35,36,37,38,39,40,41,42,43,44,15,16,17,18,19,20,21,22,23,24,25,26,27,28,29,
	30,31,32,33,34,35,36,37,38,39,40,41,42,43,44,45,46,47,48,49,50,51,52,53,54,55,56,57,58,59,
	60,61,62,63,64,65,66,67,68,69,70,71,72,73,74, 0, 1, 2, 3, 4, 5, 6, 7, 8, 9,10,11,12,13,14,
	45,46,47,48,49,50,51,52,53,54,55,56,57,58,59,15,16,17,18,19,20,21,22,23,24,25,26,27,28,29,
	30,31,32,33,34,35,36,37,38,39,40,41,42,43,44,45,46,47,48,49,50,51,52,53,54,55,56,57,58,59,
};

#define P0 (1<<9)
#define P1 (1<<10)
#define P2 (1<<11)
#define P3 (1<<12)
#define P4 (1<<13)
#define P5 (1<<14)
#define P6 (1<<1)
#define P7 (1<<2)
#define P8 (1<<3)
#define P9 (1<<4)
#define PA (1<<5)
#define PB (1<<6)

static const uint16_t high_byte_pin[] =
{
/*
for line in range(0, n_values, 30):
    print("\t" + ''.join('P{:X},'.format(n%12) for n in scattered[line:line+30]))
*/
	P4,P4,P4,P4,P4,P4,P4,P4,P4,P4,P4,P4,P4,P4,P4,P4,P4,P4,P4,P4,P4,P4,P4,P4,P4,P4,P4,P4,P4,P4,
	P0,P0,P0,P0,P0,P0,P0,P0,P0,P0,P0,P0,P0,P0,P0,P3,P3,P3,P3,P3,P3,P3,P3,P3,P3,P3,P3,P3,P3,P3,
	P3,P3,P3,P3,P3,P3,P3,P3,P3,P3,P3,P3,P3,P3,P3,P3,P3,P3,P3,P3,P3,P3,P3,P3,P3,P3,P3,P3,P3,P3,
	P3,P3,P3,P3,P3,P3,P3,P3,P3,P3,P3,P3,P3,P3,P3,P3,P3,P3,P3,P3,P3,P3,P3,P3,P3,P3,P3,P3,P3,P3,
	P0,P0,P0,P0,P0,P0,P0,P0,P0,P0,P0,P0,P0,P0,P0,P1,P1,P1,P1,P1,P1,P1,P1,P1,P1,P1,P1,P1,P1,P1,
	P1,P1,P1,P1,P1,P1,P1,P1,P1,P1,P1,P1,P1,P1,P1,P1,P1,P1,P1,P1,P1,P1,P1,P1,P1,P1,P1,P1,P1,P1,
	P1,P1,P1,P1,P1,P1,P1,P1,P1,P1,P1,P1,P1,P1,P1,P1,P1,P1,P1,P1,P1,P1,P1,P1,P1,P1,P1,P1,P1,P1,
	P0,P0,P0,P0,P0,P0,P0,P0,P0,P0,P0,P0,P0,P0,P0,PA,PA,PA,PA,PA,PA,PA,PA,PA,PA,PA,PA,PA,PA,PA,
	PA,PA,PA,PA,PA,PA,PA,PA,PA,PA,PA,PA,PA,PA,PA,PA,PA,PA,PA,PA,PA,PA,PA,PA,PA,PA,PA,PA,PA,PA,
	PA,PA,PA,PA,PA,PA,PA,PA,PA,PA,PA,PA,PA,PA,PA,PA,PA,PA,PA,PA,PA,PA,PA,PA,PA,PA,PA,PA,PA,PA,
	P0,P0,P0,P0,P0,P0,P0,P0,P0,P0,P0,P0,P0,P0,P0,P2,P2,P2,P2,P2,P2,P2,P2,P2,P2,P2,P2,P2,P2,P2,
	P2,P2,P2,P2,P2,P2,P2,P2,P2,P2,P2,P2,P2,P2,P2,P2,P2,P2,P2,P2,P2,P2,P2,P2,P2,P2,P2,P2,P2,P2,
	P2,P2,P2,P2,P2,P2,P2,P2,P2,P2,P2,P2,P2,P2,P2,P2,P2,P2,P2,P2,P2,P2,P2,P2,P2,P2,P2,P2,P2,P2,
	P0,P0,P0,P0,P0,P0,P0,P0,P0,P0,P0,P0,P0,P0,P0,P4,P4,P4,P4,P4,P4,P4,P4,P4,P4,P4,P4,P4,P4,P4,
	P4,P4,P4,P4,P4,P4,P4,P4,P4,P4,P4,P4,P4,P4,P4,P4,P4,P4,P4,P4,P4,P4,P4,P4,P4,P4,P4,P4,P4,P4,
	P6,P6,P6,P6,P6,P6,P6,P6,P6,P6,P6,P6,P6,P6,P6,P6,P6,P6,P6,P6,P6,P6,P6,P6,P6,P6,P6,P6,P6,P6,
	P8,P8,P8,P8,P8,P8,P8,P8,P8,P8,P8,P8,P8,P8,P8,P7,P7,P7,P7,P7,P7,P7,P7,P7,P7,P7,P7,P7,P7,P7,
	P7,P7,P7,P7,P7,P7,P7,P7,P7,P7,P7,P7,P7,P7,P7,P7,P7,P7,P7,P7,P7,P7,P7,P7,P7,P7,P7,P7,P7,P7,
	P7,P7,P7,P7,P7,P7,P7,P7,P7,P7,P7,P7,P7,P7,P7,P7,P7,P7,P7,P7,P7,P7,P7,P7,P7,P7,P7,P7,P7,P7,
	P8,P8,P8,P8,P8,P8,P8,P8,P8,P8,P8,P8,P8,P8,P8,P9,P9,P9,P9,P9,P9,P9,P9,P9,P9,P9,P9,P9,P9,P9,
	P9,P9,P9,P9,P9,P9,P9,P9,P9,P9,P9,P9,P9,P9,P9,P9,P9,P9,P9,P9,P9,P9,P9,P9,P9,P9,P9,P9,P9,P9,
	P9,P9,P9,P9,P9,P9,P9,P9,P9,P9,P9,P9,P9,P9,P9,P9,P9,P9,P9,P9,P9,P9,P9,P9,P9,P9,P9,P9,P9,P9,
	P8,P8,P8,P8,P8,P8,P8,P8,P8,P8,P8,P8,P8,P8,P8,PB,PB,PB,PB,PB,PB,PB,PB,PB,PB,PB,PB,PB,PB,PB,
	PB,PB,PB,PB,PB,PB,PB,PB,PB,PB,PB,PB,PB,PB,PB,PB,PB,PB,PB,PB,PB,PB,PB,PB,PB,PB,PB,PB,PB,PB,
	PB,PB,PB,PB,PB,PB,PB,PB,PB,PB,PB,PB,PB,PB,PB,PB,PB,PB,PB,PB,PB,PB,PB,PB,PB,PB,PB,PB,PB,PB,
	P8,P8,P8,P8,P8,P8,P8,P8,P8,P8,P8,P8,P8,P8,P8,P5,P5,P5,P5,P5,P5,P5,P5,P5,P5,P5,P5,P5,P5,P5,
	P5,P5,P5,P5,P5,P5,P5,P5,P5,P5,P5,P5,P5,P5,P5,P5,P5,P5,P5,P5,P5,P5,P5,P5,P5,P5,P5,P5,P5,P5,
	P5,P5,P5,P5,P5,P5,P5,P5,P5,P5,P5,P5,P5,P5,P5,P5,P5,P5,P5,P5,P5,P5,P5,P5,P5,P5,P5,P5,P5,P5,
	P8,P8,P8,P8,P8,P8,P8,P8,P8,P8,P8,P8,P8,P8,P8,P6,P6,P6,P6,P6,P6,P6,P6,P6,P6,P6,P6,P6,P6,P6,
	P6,P6,P6,P6,P6,P6,P6,P6,P6,P6,P6,P6,P6,P6,P6,P6,P6,P6,P6,P6,P6,P6,P6,P6,P6,P6,P6,P6,P6,P6,
};

void SysTick_Handler(void)
{
	precomp_dithering(cur->transpose, cur->low_bytes, residual, N_VALUES_PER_STRIP);
	bitbang_ws2801(cur->transpose, N_VALUES_PER_STRIP, CLK_MASK, GPIOB);
}


static void init(void)
{
	int i;
	for (i=0; i<N_VALUES; i++)
		residual[i] = i*153;
	cur = &frame_a;
	next = &frame_b;

	clock48mhz();
	RCC->AHBENR |= RCC_AHBENR_GPIOAEN | RCC_AHBENR_GPIOBEN; 	// enable the clock to GPIOA
	GPIOA->ODR = 0;
	GPIOA->MODER = SWD;

	GPIOB->ODR = 0;
	GPIOB->MODER = O(0)|O(1)|O(2)|O(3)|O(4)|O(5)|O(6)|O(7)|O(8)|O(9)|O(10)|O(11)|O(12)|O(13)|O(14)|O(15);

	usart2_rx_pa3_dma5_enable(recv_buf, RECV_BUF_SZ, 48e6/2e6);
	enable_sys_tick(SYS_TICK_FRAMERATE);
}

static volatile uint8_t *recv_p=recv_buf, *recv_end=recv_buf;

static void dma_wait(void)
{
	if (recv_p == &recv_buf[RECV_BUF_SZ])
		recv_p = recv_end = &recv_buf[0];

	while(recv_p == recv_end)
	{
		recv_end = &recv_buf[RECV_BUF_SZ-DMA1_Channel5->CNDTR];
		if (recv_p > recv_end)
			recv_end = &recv_buf[RECV_BUF_SZ];
	}	
}

enum
{
	GOOD,
	GOOD_00,
	GOOD_01_FE,
	GOOD_FF,
	GOOD_FFFF,
	GOOD_FFFFFF,
	BAD,
	BAD_FF,
	BAD_FFFF,
	BAD_FFFFFF,

	STATE_COUNT,

	GOOD_RETURN,
	BAD_RETURN,
};

enum
{
	IN_00,
	IN_01_EF,
	IN_F0,
	IN_F1_FE,
	IN_FF,
};

static const uint8_t fsm[STATE_COUNT][8] =
{
	[GOOD]        = {  [IN_00] = GOOD_00, [IN_01_EF] = GOOD_01_FE, [IN_F0] = GOOD_01_FE , [IN_F1_FE] = GOOD_01_FE, [IN_FF] = GOOD_FF      , },
	[GOOD_00]     = {  [IN_00] = GOOD   , [IN_01_EF] = GOOD      , [IN_F0] = GOOD       , [IN_F1_FE] = GOOD      , [IN_FF] = GOOD         , },
	[GOOD_01_FE]  = {  [IN_00] = GOOD   , [IN_01_EF] = GOOD      , [IN_F0] = GOOD       , [IN_F1_FE] = GOOD      , [IN_FF] = BAD_FF       , },
	[GOOD_FF]     = {  [IN_00] = GOOD   , [IN_01_EF] = GOOD      , [IN_F0] = GOOD       , [IN_F1_FE] = GOOD      , [IN_FF] = GOOD_FFFF    , },
	[GOOD_FFFF]   = {  [IN_00] = BAD    , [IN_01_EF] = BAD       , [IN_F0] = BAD        , [IN_F1_FE] = BAD       , [IN_FF] = GOOD_FFFFFF  , },
	[GOOD_FFFFFF] = {  [IN_00] = BAD    , [IN_01_EF] = BAD       , [IN_F0] = GOOD_RETURN, [IN_F1_FE] = BAD       , [IN_FF] = BAD_FFFFFF   , },
	[BAD]         = {  [IN_00] = BAD    , [IN_01_EF] = BAD       , [IN_F0] = BAD        , [IN_F1_FE] = BAD       , [IN_FF] = BAD_FF       , },
	[BAD_FF]      = {  [IN_00] = BAD    , [IN_01_EF] = BAD       , [IN_F0] = BAD        , [IN_F1_FE] = BAD       , [IN_FF] = BAD_FFFF     , },
	[BAD_FFFF]    = {  [IN_00] = BAD    , [IN_01_EF] = BAD       , [IN_F0] = BAD        , [IN_F1_FE] = BAD       , [IN_FF] = BAD_FFFFFF   , },
	[BAD_FFFFFF]  = {  [IN_00] = BAD    , [IN_01_EF] = BAD       , [IN_F0] = BAD_RETURN , [IN_F1_FE] = BAD       , [IN_FF] = BAD_FFFFFF   , },

};

static int read_next_frame(void)
{
	int i, c;

	memset(next, 0, sizeof(frame_t));

	for(i=0; i<N_VALUES; i++)
	{
		if (recv_p == recv_end)
			dma_wait();

		c = *recv_p++;
		next->low_bytes[low_byte_index[i]] = c;

		if (recv_p == recv_end)
			dma_wait();

		c |= (*recv_p++)<<8;

		if (c > 0xff00)
			break;

		c >>= 8;

		transposed_t *t = &next->transpose[high_byte_index[i]];
		int pin = high_byte_pin[i];
		//write_value(t, pin, c); // faster, but there's plenty cycle budget
		if (c & 0x01)
			t->bit0 |= pin;
		if (c & 0x02)
			t->bit1 |= pin;
		if (c & 0x04)
			t->bit2 |= pin;
		if (c & 0x08)
			t->bit3 |= pin;
		if (c & 0x10)
			t->bit4 |= pin;
		if (c & 0x20)
			t->bit5 |= pin;
		if (c & 0x40)
			t->bit6 |= pin;
		if (c & 0x80)
			t->bit7 |= pin;
	}

	int s=GOOD;

	if (c == 0xffff)
		s = GOOD_FFFF;
	else if (c > 0xff00)
		s = BAD_FF;

	for(;;)
	{
		if (recv_p == recv_end)
			dma_wait();

		c = *recv_p++;

		if (c == 0)
			i = IN_00;
		else if (c < 0xf0)
			i = IN_01_EF;
		else if (c == 0xf0)
			i = IN_F0;
		else if (c == 0xff)
			i = IN_FF;
		else
			i = IN_F1_FE;

		s = fsm[s][i];

		if (s == GOOD_RETURN)
			return 1;
		else if (s == BAD_RETURN)
			return 0;
	}
}

int main(void)
{
	init();
	for(;;)
	{
		frame_t *tmp = cur;
		cur = next; /* swap is not atomic, but only the assignment of cur needs to be */
		next = tmp;
		while (! read_next_frame() );
	}
}

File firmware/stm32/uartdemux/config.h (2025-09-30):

#ifndef CONFIG_H
#define CONFIG_H

#include "util.h"

/* configurable parameters (SRAM needed: XXX) */

#ifndef N_VALUES_PER_LED
#define N_VALUES_PER_LED  (3)
#endif

#ifndef N_LEDS_PER_STRIP
#define N_LEDS_PER_STRIP (264)
#endif

//#define FOREACH_PIN(X) X(0) X(1) X(2) X(3) X(4)
#define FOREACH_PIN(X) X(4) X(3) X(2) X(1) X(0)
#define STRIP_MASK (0x1f)

#define UART_IN_BAUDRATE (4800000)
#define UART_OUT_BAUDRATE (1500000)

#define DMA_WIDTH (8)

#if (STRIP_MASK & ((1<<DMA_WIDTH)-1)) != STRIP_MASK
#error "current STRIP_MASK not supported with current DMA_WIDTH"
#endif

#endif // CONFIG_H

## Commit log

2025-09-30 switch LED strips to match chiral_sphere:distr_main & driver_compact PCBs
2025-12-22 add stm32 driver for the original polyhedrone (RGB led order)
2026-02-25 add great circles 'wiring' diagram
2026-04-29 update Makefile / production file generator script
    [pcb.kicad_pcb, pcb.kicad_sch]
2026-10-30 [padauk] add pms150g-u06 relay firmware (untested)
